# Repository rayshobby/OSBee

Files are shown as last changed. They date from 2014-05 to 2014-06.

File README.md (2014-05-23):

OpenSprinkler Bee (OSBee)
=========================

OpenSprinkler Bee (OSBee) is an open-source, Arduino-based sprinkler timer for battery-operated, latching solenoid valves. It's a great gadget for garden and lawn watering, plant and flower irrigation, and other watering applications. We provide two versions: 

- OSBee Shield: an Arduino shield with 4 independent zones
- OSBee: a standalone sprinkler timer with 4 independent zones and a 2.4GHz transceiver, powered by two AA batteries.

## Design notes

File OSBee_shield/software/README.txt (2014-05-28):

OSBeeShield is an Arduino library for OSBee Shield.

Please copy this folder to your arduino\libraries.

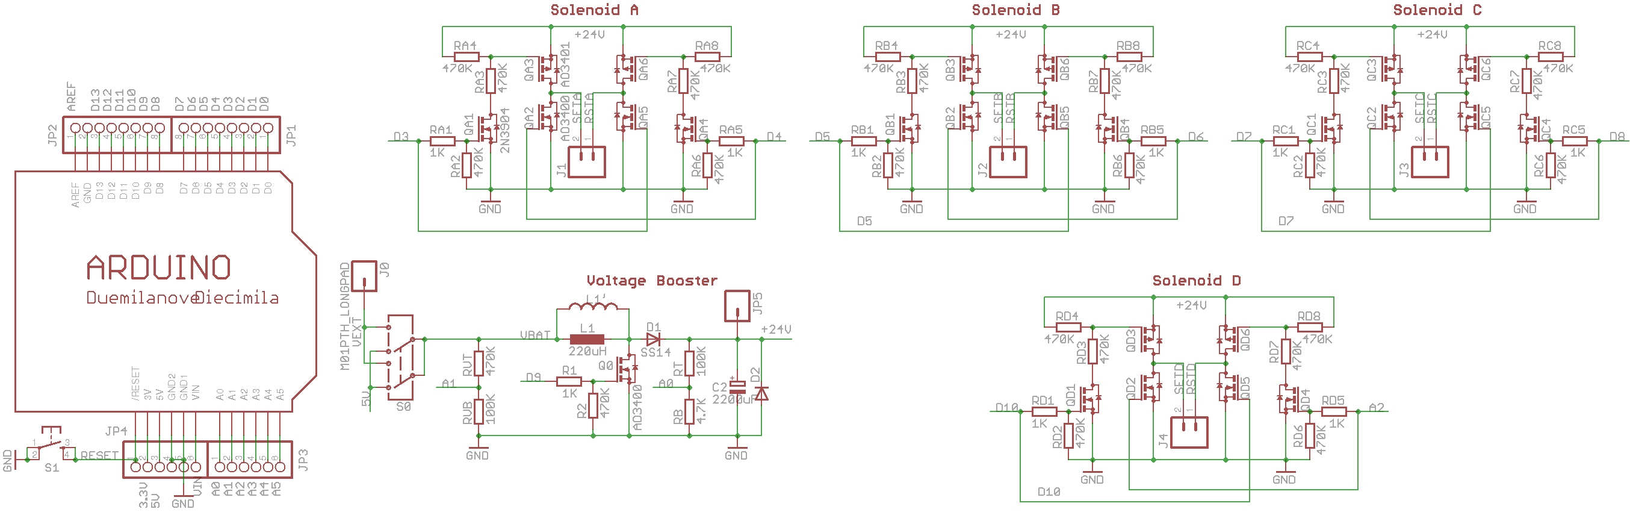
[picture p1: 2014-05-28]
OSBee_shield/hardware/osbee_shield_1.0.png

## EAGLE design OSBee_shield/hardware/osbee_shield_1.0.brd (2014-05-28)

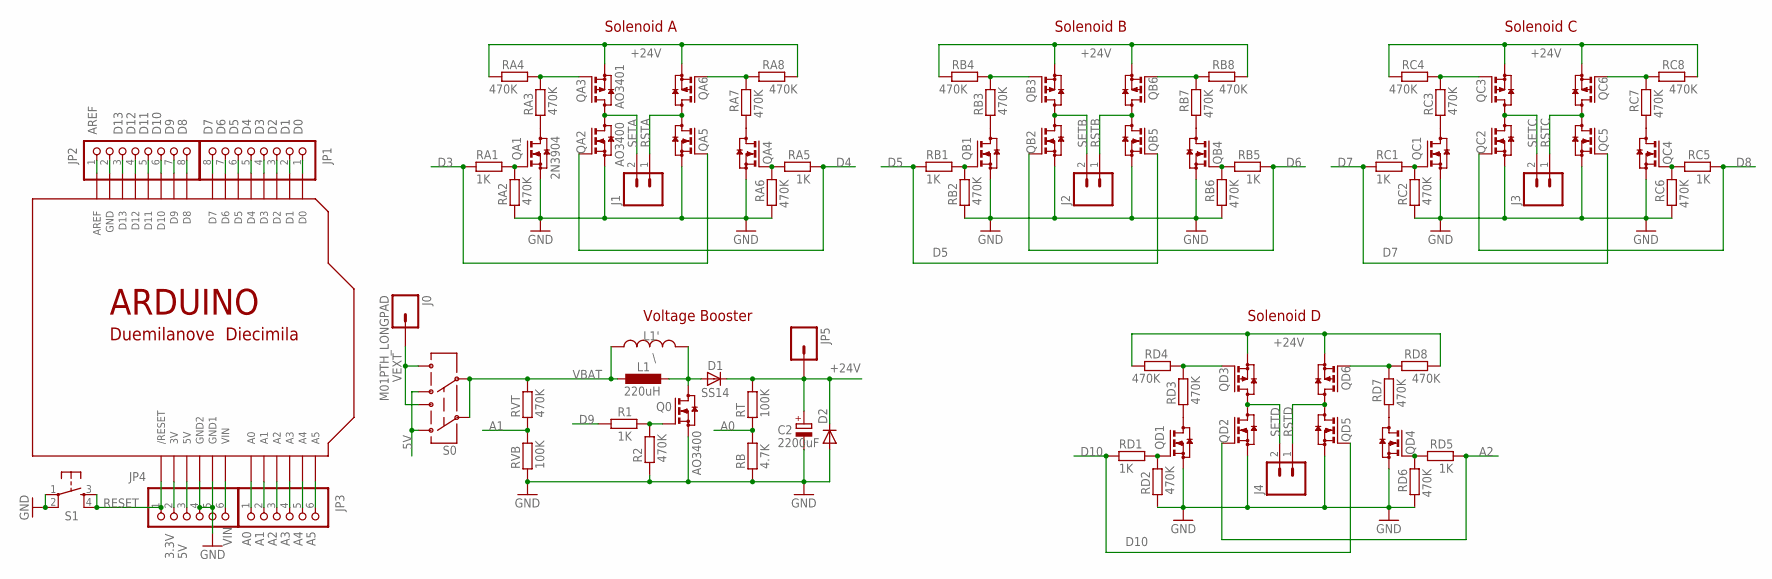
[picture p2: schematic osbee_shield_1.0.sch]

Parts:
C2: 2200uF; E5-13
D1: SS14; DO-214AC
D2: DIODE-MINIMELF; MINIMELF
J0: M01PTH_LONGPAD; 1X01_LONGPAD
J1, J2, J3, J4: M025MM; SCREWTERMINAL-5MM-2
JP1, JP2: PINHD-1X8BIG; 1X08-BIG
JP3, JP4: PINHD-1X6B; 1X06-BIG
JP5: M01SMDNS; 1X01NS
L1: 220uH; 0204/5
L1': \; INDUCTOR_D58
Q0: AO3400; SOT23
QA1: 2N3904; SOT23
QA2: AO3400; SOT23
QA3: AO3401; SOT23
QA4, QA5: BSS123; SOT23
QA6: BSS84; SOT23
QB1, QB2, QB4, QB5: BSS123; SOT23
QB3, QB6: BSS84; SOT23
QC1, QC2, QC4, QC5: BSS123; SOT23
QC3, QC6: BSS84; SOT23
QD1, QD2, QD4, QD5: BSS123; SOT23
QD3, QD6: BSS84; SOT23
R1: 1K; R0805
R2: 470K; R0805
RA1, RA5: 1K; R0805
RA2, RA3, RA4, RA6, RA7, RA8: 470K; R0805
RB: 4.7K; R0805
RB1, RB5: 1K; R0805
RB2, RB3, RB4, RB6, RB7, RB8: 470K; R0805
RC1, RC5: 1K; R0805
RC2, RC3, RC4, RC6, RC7, RC8: 470K; R0805
RD1, RD5: 1K; R0805
RD2, RD3, RD4, RD6, RD7, RD8: 470K; R0805
RT: 100K; R0805
RVB: 100K; R0805
RVT: 470K; R0805
S0: AYZ0202
S1: TAC_SWITCHPTH; TACTILE-PTH
U$1: ARDUINODUEMILANOVE-NODIM; ARDUINO-NODIM

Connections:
3.3V: JP4.2, U$1.3V
5V: JP4.3, S0.3 (1), S0.6 (4), U$1.5V
+24V: C2.+, D1.C, D2.C, JP5.1, QA3.2 (S), QA6.2 (S), QB3.2 (S), QB6.2 (S), QC3.2 (S), QC6.2 (S), QD3.2 (S), QD6.2 (S), RA4.2, RA8.2, RB4.2, RB8.2, RC4.2, RC8.2, RD4.2, RD8.2, RT.2
A0: JP3.1, RB.2, RT.1, U$1.A0
A1: JP3.2, RVB.2, RVT.1, U$1.A1
A2: JP3.3, QD2.1 (G), RD5.1, U$1.A2
A3: JP3.4, U$1.A3
A4: JP3.5, U$1.A4
A5: JP3.6, U$1.A5
AREF: JP2.1, U$1.AREF
D0: JP1.1, U$1.D0
D1: JP1.2, U$1.D1
D2: JP1.3, U$1.D2
D3: JP1.4, QA5.1 (G), RA1.1, U$1.D3
D4: JP1.5, QA2.1 (G), RA5.1, U$1.D4
D5: JP1.6, QB5.1 (G), RB1.1, U$1.D5
D6: JP1.7, QB2.1 (G), RB5.1, U$1.D6
D7: JP1.8, QC5.1 (G), RC1.1, U$1.D7
D8: JP2.8, QC2.1 (G), RC5.1, U$1.D8
D9: JP2.7, R1.2, U$1.D9
D10: JP2.6, QD5.1 (G), RD1.1, U$1.D10
D11: JP2.5, U$1.D11
D12: JP2.4, U$1.D12
D13: JP2.3, U$1.D13
GND: C2.-, D2.A, JP4.4, JP4.5, Q0.2 (S), QA1.2 (S), QA2.2 (S), QA4.2 (S), QA5.2 (S), QB1.2 (S), QB2.2 (S), QB4.2 (S), QB5.2 (S), QC1.2 (S), QC2.2 (S), QC4.2 (S), QC5.2 (S), QD1.2 (S), QD2.2 (S), QD4.2 (S), QD5.2 (S), R2.1, RA2.1, RA6.1, RB.1, RB2.1, RB6.1, RC2.1, RC6.1, RD2.1, RD6.1, RVB.1, S1.1, S1.2, U$1.GND1, U$1.GND2
unnamed: QA1.3 (D), RA3.1
unnamed: Q0.1 (G), R1.1, R2.2
unnamed: QB1.1 (G), RB1.2, RB2.2
unnamed: JP2.2, U$1.GND
unnamed: QB1.3 (D), RB3.1
unnamed: QB3.1 (G), RB3.2, RB4.1
unnamed: QA1.1 (G), RA1.2, RA2.2
unnamed: QB4.1 (G), RB5.2, RB6.2
unnamed: QA3.1 (G), RA3.2, RA4.1
unnamed: QA4.1 (G), RA5.2, RA6.2
unnamed: D1.A, L1.2, L1'.P$2 (2), Q0.3 (D)
unnamed: QB4.3 (D), RB7.1
unnamed: QA4.3 (D), RA7.1
unnamed: QA6.1 (G), RA7.2, RA8.1
unnamed: QB6.1 (G), RB7.2, RB8.1
unnamed: QC1.1 (G), RC1.2, RC2.2
unnamed: QC1.3 (D), RC3.1
unnamed: QC3.1 (G), RC3.2, RC4.1
unnamed: QC4.1 (G), RC5.2, RC6.2
unnamed: QC4.3 (D), RC7.1
unnamed: QC6.1 (G), RC7.2, RC8.1
unnamed: QD1.1 (G), RD1.2, RD2.2
unnamed: QD1.3 (D), RD3.1
unnamed: QD3.1 (G), RD3.2, RD4.1
unnamed: QD4.1 (G), RD5.2, RD6.2
unnamed: QD4.3 (D), RD7.1
unnamed: QD6.1 (G), RD7.2, RD8.1
RESET: JP4.1, S1.3, S1.4, U$1.RESET (/RESET)
RSTA: J1.1, QA5.3 (D), QA6.3 (D)
RSTB: J2.1, QB5.3 (D), QB6.3 (D)
RSTC: J3.1, QC5.3 (D), QC6.3 (D)
RSTD: J4.1, QD5.3 (D), QD6.3 (D)
SETA: J1.2, QA2.3 (D), QA3.3 (D)
SETB: J2.2, QB2.3 (D), QB3.3 (D)
SETC: J3.2, QC2.3 (D), QC3.3 (D)
SETD: J4.2, QD2.3 (D), QD3.3 (D)
VBAT: L1.1, L1'.P$1 (1), RVT.2, S0.2, S0.5
VEXT: J0.1, S0.1 (3), S0.4 (6)
VIN: JP4.6, U$1.VIN

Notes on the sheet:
Voltage Booster
Solenoid A
Solenoid B
Solenoid C
Solenoid D

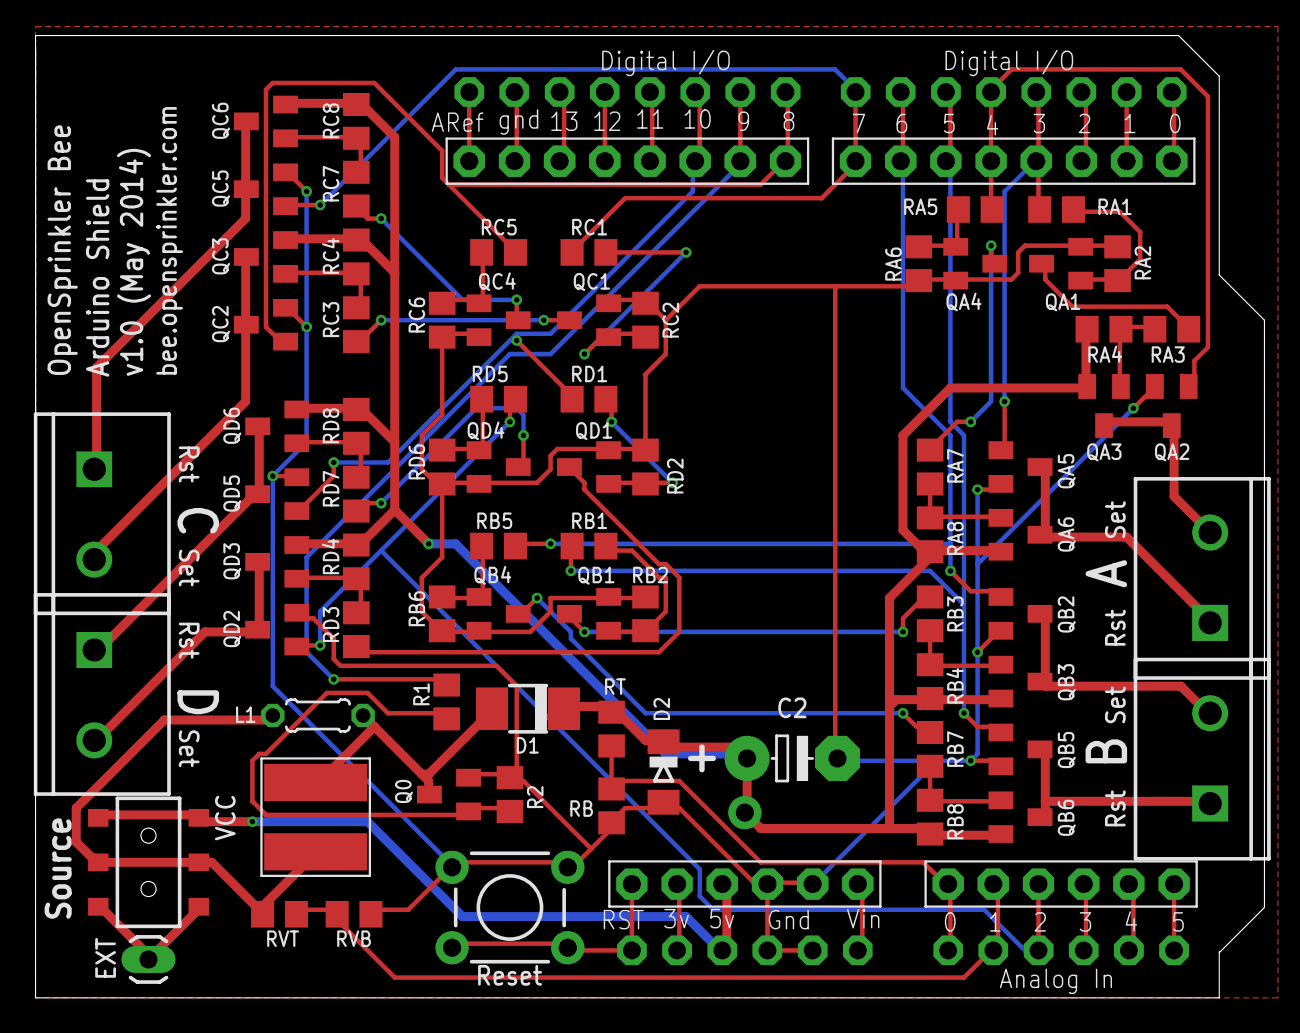
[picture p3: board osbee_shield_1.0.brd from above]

Board: 2 copper layers, 69.1 x 54.1 mm, 81 parts (0 on the bottom side), 64 nets.

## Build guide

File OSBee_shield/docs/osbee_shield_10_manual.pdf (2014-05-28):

### OpenSprinkler Bee (OSBee) Arduino Shield v1.0 User Manual

(Updated May 28, 2014)

### Contents

### Introduction

OpenSprinkler Bee (OSBee) (http://bee.opensprinkler.com/) Arduino shield is an open-source Arduino shield for switching battery-operated, latching sprinkler valves. It’s an easy and low-cost solution to transform your Arduino into a flexible sprinkler controller with 4 independent zones, for garden and lawn watering, plant and flower irrigation, and other watering applications. By stacking additional Arduino shields, you can enable sensing, web-based control, or wireless control as well.

The OSBee Arduino Shield includes one assembled and tested circuit board. Arduino is NOT included.

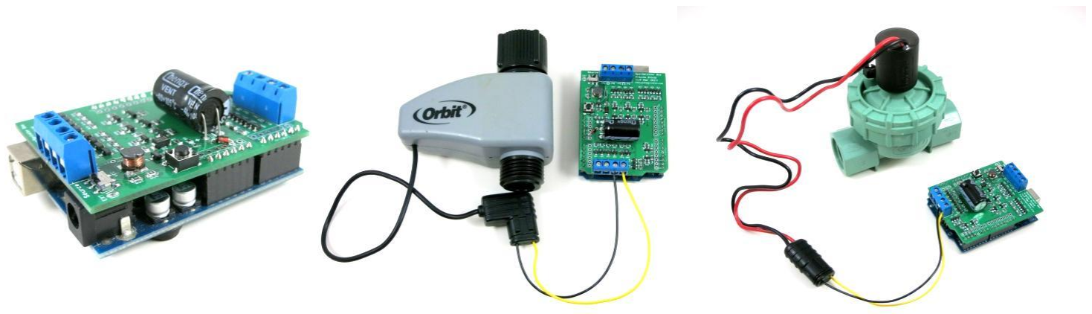
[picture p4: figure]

To get started, you will also need the following, which are NOT included in the kit and have to be purchased separately.
- An Arduino (any version)
- Up to 4 battery-operated, latching valves (note: DC latching valves only, not AC!). Examples:
- Orbit 58874N Yard Watering Valve (http://www.amazon.com/Orbit-58874N-Extra-Complete-Watering/dp/B003LY4I2I/) (24V, garden-hose thread, or GHT)
- Orbit 57861 battery-operated solenoid (http://www.amazon.com/Orbit-57861-Solenoid-Battery-Operated/dp/B0055PNDEU) for inline valves (17V, inline NPT)
- Hunter 9V DC solenoid (http://www.ebay.com/sch/i.html?_nkw=hunter+9v+solenoid&_sacat=0&_from=R40) (9V, inline NPT)

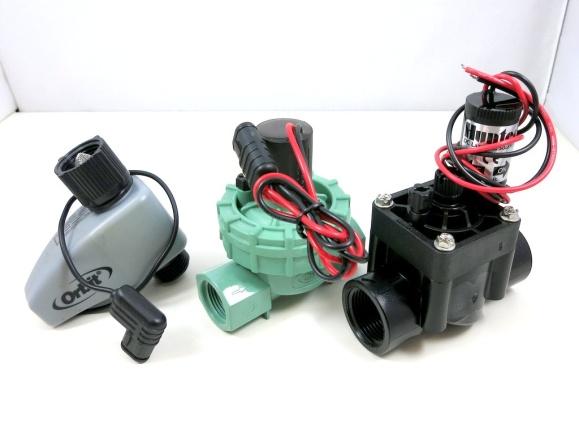
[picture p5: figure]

Battery-operated, latching DC valves are different from AC valves in that they usually have special plugs, or have two wires that are colored differently (i.e has polarity). Each valve uses a latching solenoid and only draws power when it opens or closes. No power is drawn when it remains in the same state. The latching solenoid is made of a single coil: apply a positive voltage is on the coil, the valve opens; reverse the polarity of the voltage, the valve closes. A high impulse current (up to a couple amperes) is usually required to reliably open or close the valve.

### Hardware Interface

The image below shows a close-up image of the OSBee Shield and marks the built-in components.

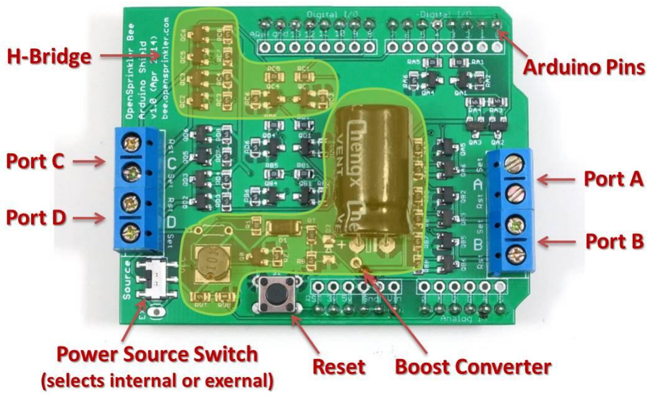
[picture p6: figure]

### Hardware Setup

### 1. Attach OSBee Shield to Arduino

WARNING: before plugging in the shield for the first time, please program the Arduino with any given OSBee Shield example. This can help prevent the pre-existing program running on Arduino to potentially cause shoot-through issues on the H-Bridge.

Insert the OSBee Shield into the Arduino. If you have other Arduino shields you’d like to stack, such as a WiFi shield or an Ethernet shield, keep OSBee Shield on the top layer. You need to find out the pins reserved by the other shields (for example, the Ethernet shield reserves pin 10 for Chip Select), and leave the corresponding pins out on the OSBee Shield. Details are explained later in this document.

### 2. Select the Power Source

The power source switch (lower-left corner) is used to select between Arduino’s VCC pin (internal) or an external power source, such as a battery. When using an external source, solder a wire from the ‘EXT’ pin to the source’s positive lead, and any ‘GND’ pin to the source’s negative lead (i.e. share the ground). If your external source is also used to power the Arduino, it’s recommended that you connect a 1ohm resistor (included in the kit) in series on the EXT wire to limit the current draw.

The internal source (VCC) is useful for testing, but keep in mind that some Arduinos (particularly the Pro Mini) have built-in fuse that prevent drawing high current from the VCC pin. During operation, the boost converter on OSBee Sheild needs to momentarily draw up to several hundred milliamps of current. To avoid triggering the fuse, using an external source is recommended. Also, when using the internal source, if you encounter any trouble uploading a program to Arduino (such as an Inappropriate ioctl for device error), you can solder the included 1ohm resistor between EXT and the +5V pin, then set the power source selector to EXT. See the picture on the right. This will limit the current
draw from the VCC pin.

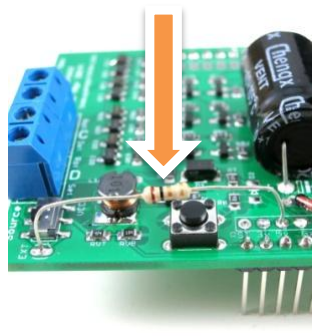
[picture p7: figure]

The boost converter can work with any input voltage between 1V DC to 6V DC. Higher input voltage results in faster boosting time but also higher current draw, and vice versa. The current draw / boosting time can also be adjusted in software by using the OSBee::setDutyCycle() function – smaller duty cycle reduces the current draw but also slows down the boosting time.

### 3. Wiring Sprinkler Valves

OSBee Shield supports four independent zones. These are marked ports A, B, C and D. Each port has two pins named Set and Rst (Reset). Connect your sprinkler valve’s positive wire (red colored) to the Set pin, and negative (black colored) to the Rst pin. If you accidentally reversed the polarity, you won’t damage anything – it will just reverse the logic (i.e. ‘opening’ the valve actually closes it etc.).

If your sprinkler valve comes with a special plug, such as the Orbit 58874N valve, you can connect it as follow: the top pin on the plug is usually the positive wire, and the bottom pin is the negative wire. You can cut two pieces of wires (22 to 24 AWG recommended), strip the wires; then insert one end to the plug, the other end to the screw terminals on OSBee Shield, as shown in the picture on below.

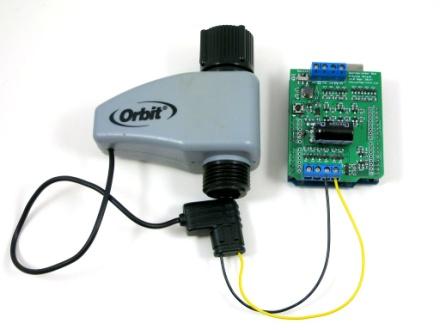
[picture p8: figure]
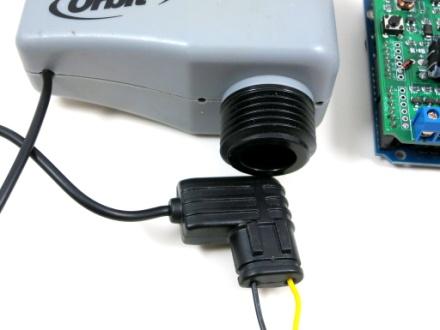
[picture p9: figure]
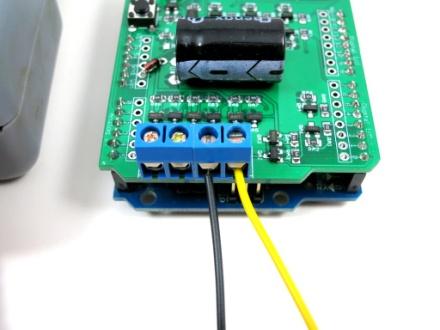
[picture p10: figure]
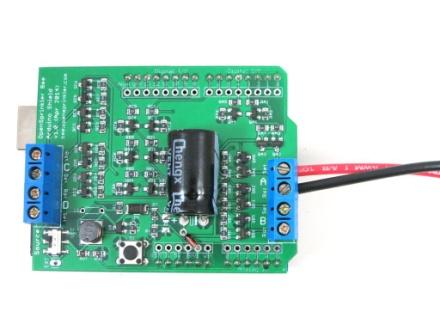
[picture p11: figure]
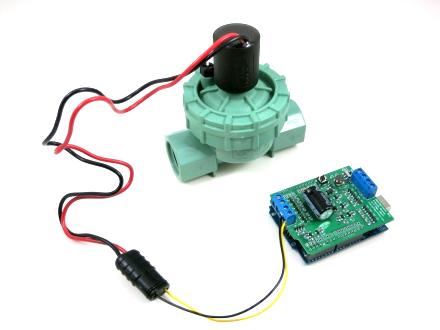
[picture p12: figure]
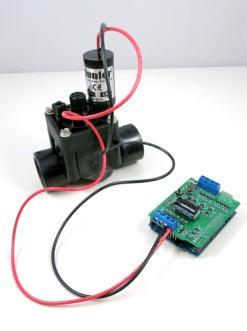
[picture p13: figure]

### Software Setup

### 1. Pin Assignment

OSBee Shield makes use of the following pins on the Arduino:

- PortA: D3 (set), D4 (rst); PortB: D5, D6; PortC: D7, D8; PortD: D10, A2 (i.e. D16).
- D9: boost converter PWM pin.
- A0: boost converter feedback pin.
- A1: battery voltage feedback pin.

Precaution: make sure you NEVER set the pair of pins on the same port high at the same time. For example, setting D3 and D4 high at the same time can cause damage to the Port A H-Bridge.

### 2. Arduino Library and Demo Programs

An Arduino library for OSBee Shield is provided, with several examples to show how to use the library. One example is a simple testing program that opens each valve for 5 seconds, one after another. The second is a program-based scheduling algorithm – it allows the user to use Serial input to set multiple sprinkler programs. The third is a web-based program – it uses the standard Arduino Ethernet shield to create a simple web interface, and allows the user to click buttons on the webpage to open / close valves. More full-featured programs will be added in the future. Here is a brief summary of the library:

- Include the library by: #include<OSBee.h>
- Define an OSBee object such as: OSBee osb;
- In the Arduino setup() function, call: osb.begin();
- To open a valve, such as Port A, use either osb.open(0); or osb.open(‘A’);
- To close a valve, such as Port B, use either osb.close(1); or osb.close(‘B’);
- To read the external source voltage, use osb.getBattVoltage();

There are also several parameters you can adjust (optional):

- Set boost voltage (e.g. to 16.0V): osb.setVoltage(16.0);
- Set pulse length (e.g. to 25ms): osb.setPulseLength(25);
- Set PWM duty cycle (e.g. to 20%): osb.setDutyCycle(20);

Generally, the boost voltage is between 9V to 22V, the pulse length between 25ms to 200ms, and the PWM duty cycle between 10 to 50. The pulse length controls how long the H-Bridge will open and should be kept as short as possible. The duty cycle affects the current draw and boosting time. If your valve cannot reliably open / close, first consider increasing the boost voltage to 22.0; if it still doesn’t work, gradually increase the pulse length. If the boost converter draws too much current that triggers a reset of the Arduino, consider reducing the duty cycle.

If you are not sure about the correct voltage and timing, don’t worry about it. Because the circuit builds up charges into the on-board capacitor and supplies the voltage to your valve from there, you won’t damage your valve even if you used a voltage higher than necessary, or timing longer than necessary. There is no persistent high voltage on the circuit, and the capacitor can only store a limited amount of charge, so it’s unlikely you will damage your valve.

Warning: leaving the valve open unintentionally and not being able to close it can lead to water waste and even worse, flood damage. For best practice, periodically perform a ‘close’ operation on all valves to make sure they are off. Also, before opening a valve, you can use getBattVoltage to check the battery voltage and make sure the battery is in good condition to close the valve later.

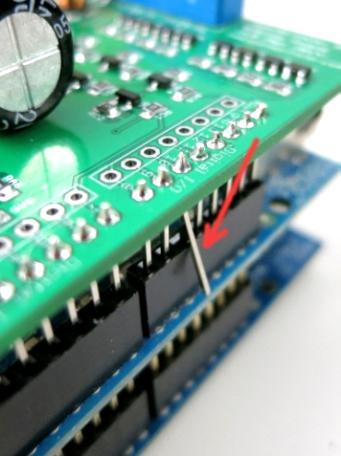
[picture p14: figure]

### 3. Using OSBee Shield with other Arduino Shields

It’s possible to use OSBee Shield with other Arduino Shields, such as the Ethernet Shield, WiFi Shield etc. It’s important to find out what pins the other shields require, and avoid any pin conflict. For example, the Ethernet shield uses D10 as Chip Select. Because D10 is also used by OSBee Shield for Port D Set pin, you have to leave this pin out on the OSBee Shield, which will disable Port D functionality. To leave the pin out, you can either cut this pin on OSBee Shield, or bend the pin so that it’s not physically inserted into the female pin headers (see picture on the right). You can also cut the PCB trace of D10 (but this will result in permanent change).

### Specifications

- | Source Voltage: | 1.8V DC to 6V DC (selectable from either internal VCC or external)
- | Boost Voltage: | up to 24V DC.
- | Output Current: | > 10A impulse; > 3A continuous.
- | Number of Zones: | 4 independent.
- | Size: | 70mm x 55mm x 28mm (2.75” x 2.2” x 1.1”)
- | Weight: | 28g (1oz) w/o Arduino

### Terms and Conditions

OpenSprinkler Bee (OSBee) is an open-source project. The hardware design and software code are made publicly available under the Creative Commons Attribution-ShareAlike (CC BY--SA) 3.0 (https://creativecommons.org/licenses/by-sa/3.0/us/) license. The product is open-source for educational purpose. The hardware and software are provided as is. We (Rayshobby LLC) are not responsible for any damage or accident that may occur due to either hardware or software error, or during the assembly, use, and modification of OSBee Shield.

### Open-Source Links

- OSBee Shield Github Repository (https://github.com/rayshobby/OSBee)
- OSBee homepage (http://bee.opensprinkler.com/)

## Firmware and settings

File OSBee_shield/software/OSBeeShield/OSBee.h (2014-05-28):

/* 
   An Arduino Library for OSBee Shield
   http://bee.opensprinkler.com
   
   License: Creative Commons CC-SA 3.0
   
   Written by : Ray Wang (Rayshobby LLC)
   info@rayshobby.net
   
*/

#ifndef _OSBEE_H
#define _OSBEE_H

// Default boost voltage, unit is Volt
#define DEFAULT_BOOST_VOLTAGE 16.0

// Default duty cycle (percentage)
#define DEFAULT_BOOST_DUTY    25

// Default pulse length, unit is millisecond
#define DEFAULT_PULSE_LENGTH  25

#define pinBOOST    9 // boost PWM pin
#define pinBOOST_FB 0 // boost feedback pin (analog pin)
#define pinBATT_FB  1 // battery voltage feedback pin (analog pin)


// Set / Rst pins for ports A, B, C, D
#define pinSET_A    3
#define pinRST_A    4
#define pinSET_B    5
#define pinRST_B    6
#define pinSET_C    7
#define pinRST_C    8
#define pinSET_D    10
#define pinRST_D    16

// Turn on serial debug messages 
//#define SERIAL_DEBUG 

class OSBee {
private:
  int voltage_level;  // analog value for boost converter feedback
  int pulse_length;   // pulse length (in milliseconds)
  int duty_cycle;     // duty cycle for PWM
  bool initialized;   
  void boost();       // boost voltage
public:
  OSBee();
  void begin();
  // set boost voltage, generally between 9 and 22
  void setVoltage(float v);
  // set pulse length (generally between 20 to 200)
  void setPulseLength(int l);
  // set duty cycle, generally between 5 and 50
  // increasing duty cycle results in higher current draw and faster boost time
  // decreasing duty cycle results in lower current draw and slower boost time
  void setDutyCycle(int c);
  void closeAll();    // close all valves
  void close(int i);  // close valve i (i = 0, 1, 2, 3, corresponding to ports A, B, C, D)
  void close(char p); // close valve p (p = 'A', 'B', 'C', 'D')
  void open(int i);   // open valve i (i = 0, 1, 2, 3, corresponding to ports A, B, C, D)
  void open(char p);  // open valve p (p = 'A', 'B, 'C', 'D')
  float getBattVoltage(); // get battery voltage
};

#endif

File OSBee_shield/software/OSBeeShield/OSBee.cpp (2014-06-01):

/* 
   An Arduino Library for OSBee Shield
   http://bee.opensprinkler.com
   
   License: Creative Commons CC-SA 3.0
   
   Written by : Ray Wang (Rayshobby LLC)
   info@rayshobby.net
   
*/
#include <wiring_private.h>
#include <Serial.h>
#include "OSBee.h"

// Constructor function
OSBee::OSBee() {
  voltage_level = 0;
  pulse_length = 0;
  duty_cycle = 0;
  initialized = false;
}

// Must call this function first
void OSBee::begin() {
  
#ifdef SERIAL_DEBUG
  Serial.begin(9600);
#endif

  // !!!!!! IMPORTANT !!!!!!
  // Must set ADC to use internal reference
  analogReference(INTERNAL); 
    
  setVoltage(DEFAULT_BOOST_VOLTAGE);
  setPulseLength(DEFAULT_PULSE_LENGTH);
  setDutyCycle(DEFAULT_BOOST_DUTY);


  // !!!!!! IMPORTANT !!!!!!
  // Set pins in output mode, and clear all pins
  pinMode(pinSET_A, OUTPUT);
  digitalWrite(pinSET_A, LOW);
  
  pinMode(pinRST_A, OUTPUT);
  digitalWrite(pinRST_A, LOW);
  
  pinMode(pinSET_B, OUTPUT);
  digitalWrite(pinSET_B, LOW);
  
  pinMode(pinRST_B, OUTPUT);
  digitalWrite(pinRST_B, LOW);

  pinMode(pinSET_C, OUTPUT);
  digitalWrite(pinSET_C, LOW);
  
  pinMode(pinRST_C, OUTPUT);
  digitalWrite(pinRST_C, LOW);

  pinMode(pinSET_D, OUTPUT);
  digitalWrite(pinSET_D, LOW);
  
  pinMode(pinRST_D, OUTPUT);
  digitalWrite(pinRST_D, LOW);
      
  // The following sets 62.5Khz PWM for pin 9 (timer 1)
  // The ideal frequency depends on the inductor, but it'll only be important if you need alot more power.
  // set prescaler to 1
  // (sbi means "set bit register", cbi means "clear bit register")
  cbi(TCCR1B, CS12);
  cbi(TCCR1B, CS11);
  sbi(TCCR1B, CS10);
  
  // set fast PWM
  cbi(TCCR1B, WGM13);
  sbi(TCCR1B, WGM12);
        
  initialized = true;
  
  // close all valves
  closeAll();
  
#ifdef SERIAL_DEBUG
  Serial.println("Initialized.");
#endif  
}

// Boost voltage
void OSBee::boost() {
  if (!initialized) return;
  
  // !!!!!! IMPORTANT !!!!!!
  // Must set ADC to use internal reference
  analogReference(INTERNAL);  

#ifdef SERIAL_DEBUG
  Serial.print("Boosting...");
#endif

  unsigned int measure;
 
  analogWrite(pinBOOST, 0);
  
  measure = analogRead(pinBOOST_FB);
  if (measure < voltage_level)
    analogWrite(pinBOOST, duty_cycle * 256 / 100);  // set duty cycle
    
  unsigned long t = millis();
  while (measure < voltage_level) {
    measure = analogRead(pinBOOST_FB);
    // set a time limit : 30 seconds
    if (millis() > t + 30000)  break;
  }
  analogWrite(pinBOOST, 0);


#ifdef SERIAL_DEBUG
  Serial.println("done.");
#endif
}

// Calculate the desired analog input reading, for a given voltage
void OSBee::setVoltage(float v) {

  // On OSBee, the boost feedback divider is 100K top, 4.7K bottom.
  // So the analog reading should be:
  // voltage * 47 / (1000 + 47) / 1.1 * 1024
  // where 1.1 is ATmega328's internal voltage reference
  voltage_level = (int)(v*41.8);

#ifdef SERIAL_DEBUG
  Serial.print("Voltage level: ");
  Serial.println(voltage_level);
#endif
}

// Set pulse length (usually between 50 to 200)
void OSBee::setPulseLength(int l) {
  pulse_length = l;
}

void OSBee::setDutyCycle(int c) {
  if (c>0 && c<=50)
    duty_cycle = c;
}

// Close all valves
void OSBee::closeAll() {
  close(0);
  close(1);
  close(2);
  close(3);
}

static byte osbee_pins[] = {pinSET_A, pinRST_A,
                            pinSET_B, pinRST_B,
                            pinSET_C, pinRST_C,
                            pinSET_D, pinRST_D};
  
// Close valve i (i = 0, 1, 2, 3, corresponding to ports A, B, C, D)
void OSBee::close(int i) {
  if(i<0 || i>3)  return;

  int set_pin = osbee_pins[i*2+0];
  int rst_pin = osbee_pins[i*2+1];
  
  digitalWrite(set_pin, LOW);
  digitalWrite(rst_pin, LOW);
  
  boost();
  
  digitalWrite(rst_pin, HIGH);
  delay(pulse_length);
  digitalWrite(rst_pin, LOW);
  
#ifdef SERIAL_DEBUG
  Serial.print("Valve ");
  Serial.print(i);
  Serial.println(" closed.");
#endif  
}

// Close valve p (p = 'A', 'B', 'C', 'D'; or 'a', 'b', 'c', 'd')
void OSBee::close(char p) {
  if (p>='A' && p<='D')
    close((int)(p - 'A'));
  else if (p>='a' && p<='d')
    close((int)(p - 'a'));
}

// Open valve i (i = 0, 1, 2, 3, corresponding to ports A, B, C, D)
void OSBee::open(int i) {
  if(i<0 || i>3)  return;
  int set_pin = osbee_pins[i*2+0];
  int rst_pin = osbee_pins[i*2+1];
  
  digitalWrite(set_pin, LOW);
  digitalWrite(rst_pin, LOW);
  
  boost();
  
  digitalWrite(set_pin, HIGH);
  delay(pulse_length);
  digitalWrite(set_pin, LOW);
  
#ifdef SERIAL_DEBUG
  Serial.print("Valve ");
  Serial.print(i);
  Serial.println(" opened.");
#endif  
}

// Open valve p (p = 'A', 'B, 'C', 'D'; or 'a', 'b', 'c', 'd')
void OSBee::open(char p) {
  if (p>='A' && p<='D')
    open((int)(p - 'A'));
  else if (p>='a' && p<='d')
    open((int)(p = 'a'));
}

// get battery voltage
float OSBee::getBattVoltage() {
  // !!!!!! IMPORTANT !!!!!!
  // Must set ADC to use internal reference
  analogReference(INTERNAL); 
  
  // On OSBee, the battery feedback divider is 470K top, 100K bottom.
  // analog reading = voltage * 100 / (100 + 470) / 1.1 * 1024
  // where 1.1 is ATmega328's internal voltage reference
  return analogRead(pinBATT_FB) * 0.00612;
}

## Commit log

2014-05-28 check in OSBee_Shield hardware design files, Arduino library, and user manual
    [osbee_shield_1.0.brd, osbee_shield_1.0.sch]
2014-06-01 fix a bug in the open by port number function
    [OSBee.cpp]

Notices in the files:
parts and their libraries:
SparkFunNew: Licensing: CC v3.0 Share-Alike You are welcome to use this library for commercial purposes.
